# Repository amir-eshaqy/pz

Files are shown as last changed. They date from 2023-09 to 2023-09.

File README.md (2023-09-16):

<h1 align="center" id="title">Arduino Power meter system with Internal PLC</h1>

<p align="center">project-image</p>

<h3><strong>Features</strong></h3>
<ul>
<li>Instant display (voltage, power factor, current, power, frequency)</li>
<li>Ability to set automation in 12 modes and 4 relays (Internal PLC)</li>
<li>Ability to connect to MATLAB software</li>
<li>Ability to connect to the battery</li>
<li>Maximum measurable voltage: 280 volts (two-phase, single-phase)</li>
<li>The maximum measurable current is 100 amperes (using CT 100:1)</li>
<li>The maximum measurable frequency is 60 Hz</li>
<li>Voltage measurement accuracy 0.1 v</li>
<li>Current measurement accuracy 0.2 A</li>
<li>The accuracy of power measurement is 0.4 W</li>
<li>Frequency measurement accuracy of 0.1 Hz</li>
<li>The accuracy of power factor measurement is 0.01%</li>
</ul>
<p><strong>point</strong>:By changing the resistances of <strong>R17</strong> and <strong>R16</strong> in <strong>PZEM</strong>, it is possible to measure the voltage of more than <strong>280 volts</strong> (This is a voltage divider circuit).</p>
<p>For example, if <strong>R17</strong> is equal to <strong>2 megaohms</strong> and <strong>R16</strong> is equal to <strong>750 ohms</strong>, the voltage can be measured up to <strong>500 volts</strong>.</p>
<p>It is also necessary to make changes in the Arduino codes, Additional information in the folder <span style="text-decoration: underline;"><strong>500 volts</strong></span></p>
*point 2:This system also supports Modbus protocol. You can add this potkal to it. And it was in contact with other industrial equipment such as HME and PLCs

____________________________________________________________________________________________
<h3><strong>required pieces ::</strong></h3>
<table border="1">
<tbody>
<tr>
<td>
<h4>Electronic Components</h4>
</td>
<td>
<blockquote>Number</blockquote>
</td>
</tr>
<tr>
<td>Arduino Nano</td>
<td>1</td>
</tr>
<tr>
<td>PZEM004t</td>
<td>1</td>
</tr>
<tr>
<td>Liquid Crystal Displays (Character LCD)</td>
<td>1</td>
</tr>
<tr>
<td>4-channel relay module</td>
<td>1</td>
</tr>
<tr>
<td>push button</td>
<td>5</td>
</tr>
<tr>
<td>switch</td>
<td>1</td>
</tr>
<tr>
<td>Potentiometer 10 kilo ohms</td>
<td>1</td>
</tr>
<tr>
<td>10 kilo ohm resistance</td>
<td>5</td>
</tr>
<tr>
<td>n-channel MOSFET</td>
<td>1</td>
</tr>
</tbody>
</table>

____________________________________________________________________________________________

<h3>Test video&nbsp;</h3>
<p>Connecting power meter to MATLAB and view the data on the chart <a href="https://youtu.be/Np4y_KRA4oQ">https://youtu.be/Np4y_KRA4oQ</a></p>
<p>voltage measurement test <a href="https://youtu.be/dCQaTeNKbkk">https://youtu.be/dCQaTeNKbkk</a></p>
<p>current measurement test <a href="https://youtu.be/r_vkd0LcIXw">https://youtu.be/r_vkd0LcIXw</a></p>
<p>Relay function test <a href="https://youtu.be/pQEmvJ6B6WI">https://youtu.be/pQEmvJ6B6WI</a></p>
<p>&nbsp;</p>
<p>&nbsp;</p>

____________________________________________________________________________________________

<h3>Internal PLC settings :</h3>
<p>To access the settings menu, we must first turn the <strong>MODE</strong> key on and set the required parameters with the <strong>arrow keys</strong>.</p>
<table border="1">
<tbody>
<tr>
<td><strong>parameter in the settings menu</strong></td>
<td><strong>use</strong></td>
</tr>
<tr>
<td>OVER Voltage</td>
<td>Maximum voltage limit</td>
</tr>
<tr>
<td>LOW Voltage</td>
<td>Minimum voltage&nbsp;</td>
</tr>
<tr>
<td>OVER Current</td>
<td>maximum current limit</td>
</tr>
<tr>
<td>LOW Frequency</td>
<td>minimum frequency</td>
</tr>
<tr>
<td>OVER Frequency</td>
<td>Maximum frequency limit</td>
</tr>
<tr>
<td>LOW POWER FACTOR 1</td>
<td>steps, one power factors</td>
</tr>
<tr>
<td>LOW POWER FACTOR 2</td>
<td>steps, two power factors</td>
</tr>
<tr>
<td>LOW POWER FACTOR 3</td>
<td>steps, three power factors</td>
</tr>
<tr>
<td>TMS 1 SET</td>
<td>timer relay one</td>
</tr>
<tr>
<td>TMS 2 SET</td>
<td>timer relay two</td>
</tr>
<tr>
<td>TMS 3 SET</td>
<td>timer relay three</td>
</tr>
<tr>
<td>TMS 4 SET</td>
<td>timer relay four</td>
</tr>
<tr>
<td>R1</td>
<td>set the operation mode of relay one</td>
</tr>
<tr>
<td>R2</td>
<td>set the operation mode of relay two</td>
</tr>
<tr>
<td>R3</td>
<td>set the operation mode of relay three</td>
</tr>
<tr>
<td>R4</td>
<td>set the operation mode of relay four</td>
</tr>
</tbody>
</table>
<p>After making the settings, turn the <strong>MODE</strong> key to the off position so that the data is stored in the <strong>permanent memory</strong> of the controller</p>
<p>* Each relay timer unit is 100 milliseconds</p>
____________________________________________________________________________________________

<h3>A variety of performance modes (R1,R2,R3,R4):</h3>
<p>1- reverse time overcurrent function</p>
2- Additional constant time flow function<br />
3-Overvoltage function<br />
4- voltage reduction function<br />
5- frequency reduction function<br />
6- frequency increase function<br />
7- Function of the function of going out of normal mode (frequency, voltage, current)<br />
8-Function of power factor steps of one<br />
9-Function of power factor steps of two<br />
10- Function of power factor steps of three<br />
11-The operation of voltage out of normal mode<br />
12-&nbsp;Function of frequency out of normal mode</p>

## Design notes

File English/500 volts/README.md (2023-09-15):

<h4>This is the schematic and Arduino code For the power meter, the maximum voltage that can be measured is 500 volts</h4>

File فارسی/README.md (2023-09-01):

# pz
راهنما سیستم انالیزور شبکه برق به همره پی ال سی داخلی

شامل پایان نامه و بروشور  است که با مطالعه کامل انها میتوانید یه پاور انالیزور طراحی کنید.

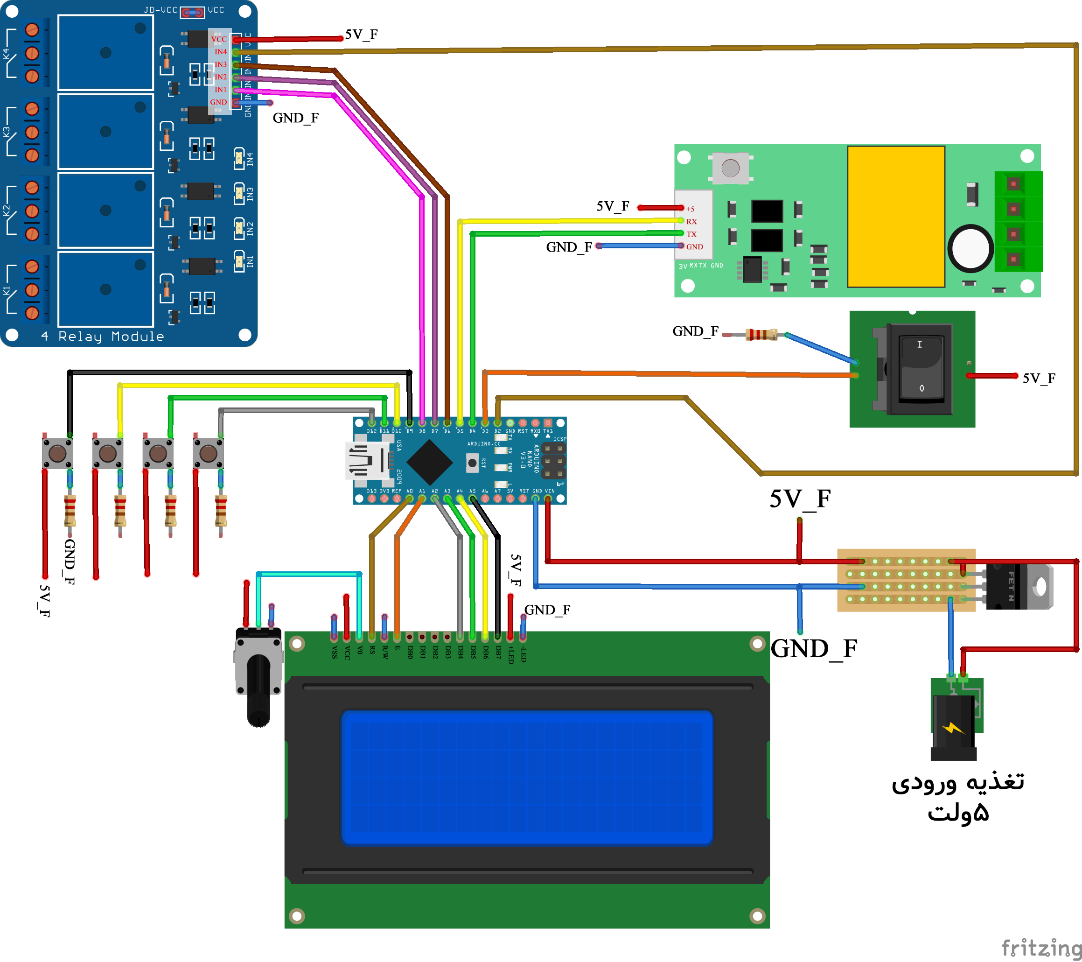
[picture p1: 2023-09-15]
فارسی/schematic.png

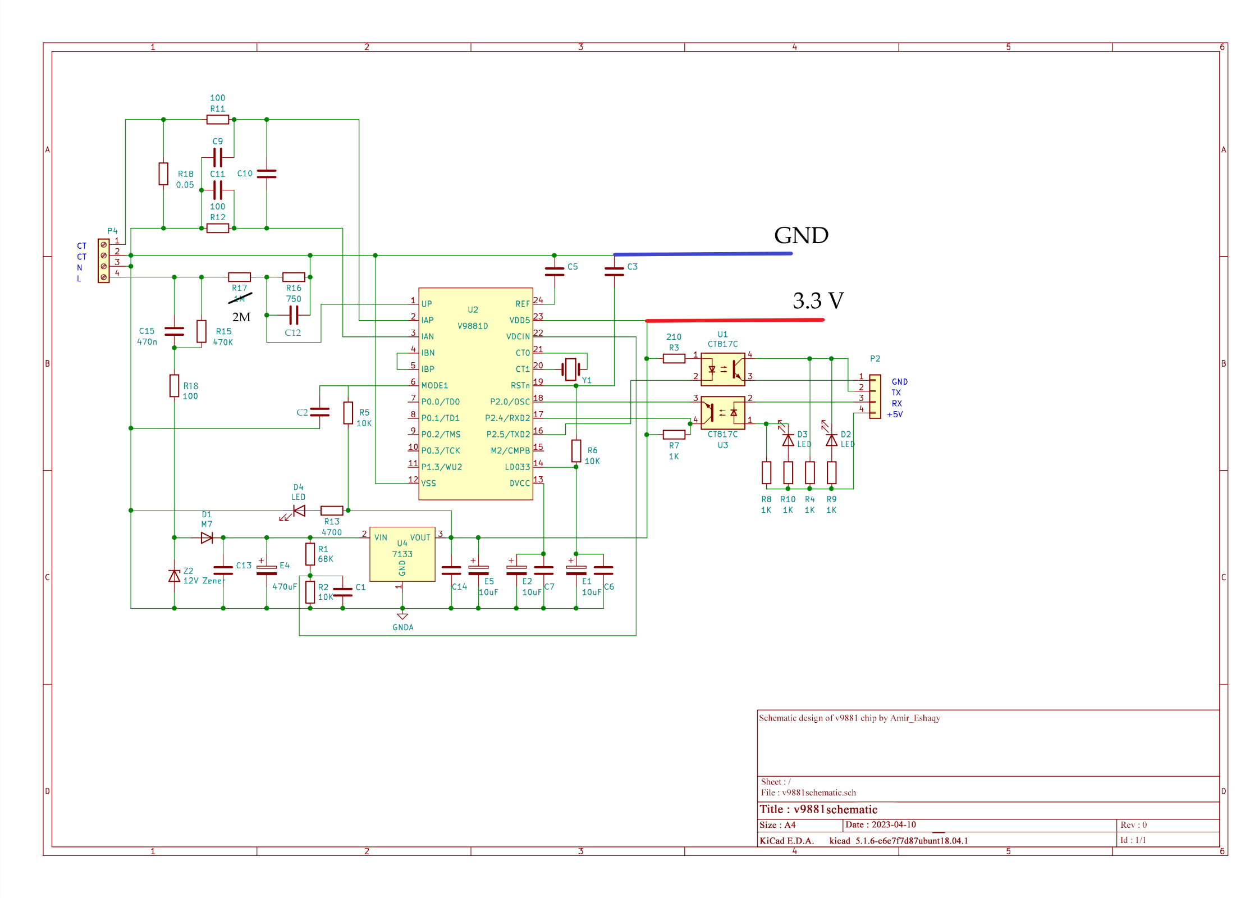
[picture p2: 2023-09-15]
فارسی/500v/PZEM schematic for 500V version.png

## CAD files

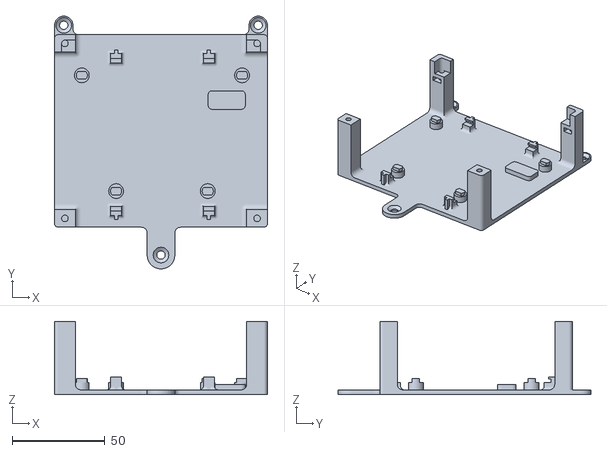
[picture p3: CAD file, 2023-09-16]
English/STL-3d-printer/OSPi_Case_Bottom.stl
115.0 x 136.5 x 39.6

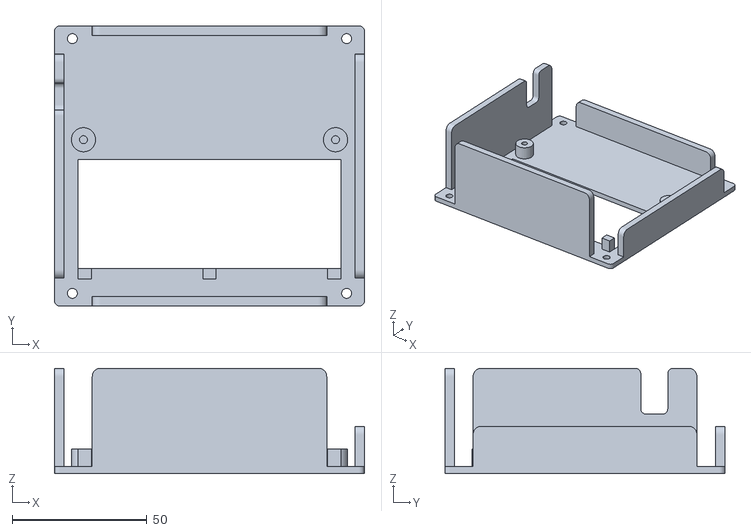
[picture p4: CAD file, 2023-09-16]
English/STL-3d-printer/OSPi_Case_Top.stl
115.0 x 104.0 x 39.1

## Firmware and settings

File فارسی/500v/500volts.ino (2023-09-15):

/*                                                               500v cod
 * Amir_eshaqy
 * 
 * telegram = amir_eshaqy
 * gmail = amir9336146433@gmail.com
 * 
 * Schematic and tutorial files on GitHub
 * GitHub = https://github.com/amir-eshaqy/pz
 * 
 */

#include <PZEM004Tv30.h>
#include <Wire.h>
#include <LiquidCrystal.h>
#include <EEPROM.h>

PZEM004Tv30 pzem(4,5);//arduino
float voltage;
float current;
float power;
float energy;
float frequency;
float pf;
//LiquidCrystal_I2C lcd(0x27,20,4); // set the LCD address to 0x3F for a 16 chars and 2 line display

LiquidCrystal lcd(A0, A1, A2, A3, A4, A5);

byte R1mood=0;
byte R2mood=0;
byte R3mood=0;
byte R4mood=0;


byte mood=3;
byte relly1=8;
byte relly2=7;
byte relly3=6;
byte relly4=2;
byte fclear=0;
int tms_set1=1;
int tms_set2=1;
int tms_set3=1;
int tms_set4=1;
int timeroc1=0;
int timeroc2=0;
int timeroc3=0;
int timeroc4=0;
float ti1=0.00;
float ti2=0.00;
float ti3=0.00;
float ti4=0.00;
byte O_V=0;
byte L_V=0;
byte O_C=0;
byte L_F=0;
byte O_F=0;
float L_PF1=0.90;
float L_PF2=0.85;
float L_PF3=0.80;
//Input & Button Logic
const int numOfInputs = 4;
const int inputPins[numOfInputs] = {12,11,10,9};
int inputState[numOfInputs];
int lastInputState[numOfInputs] = {LOW,LOW,LOW,LOW};
bool inputFlags[numOfInputs] = {LOW,LOW,LOW,LOW};
long lastDebounceTime[numOfInputs] = {0,0,0,0};
long debounceDelay = 5;

//LCD Menu Logic
const int numOfScreens = 16;
int currentScreen = 0;
String screens[numOfScreens][2] = {{"Over Voltage","Volts"}, {"Low Voltage","Volts"}, 
{"Over Current","Amper"},{"Low Frequency","Hz"},{"Over Frequency","Hz"}, {"LOW POWER FACTOR 1", "CosFi"}, {"LOW POWER FACTOR 2", "CosFi"}, {"LOW POWER FACTOR 3", "CosFi"},{"TMS1 SET", " "},{"TMS2 SET", " "},{"TMS3 SET", ""},{"TMS4 SET", " "},{"R1_Mood", " "},{"R2_Mood", " "},{"R3_Mood", " "},{"R4_Mood", " "}};

float parameters[numOfScreens];




void setup() {
 O_V=EEPROM.read(1);
 L_V=EEPROM.read(2);
 O_C=EEPROM.read(3);
 L_F=EEPROM.read(4);
 O_F=EEPROM.read(5);
 EEPROM.get(10,L_PF1);
 EEPROM.get(30,L_PF2);
 EEPROM.get(50,L_PF3);
 EEPROM.get(70,tms_set1);
 EEPROM.get(100,tms_set2);
 EEPROM.get(130,tms_set3);
 EEPROM.get(160,tms_set4);
 R1mood=EEPROM.read(190);
 R2mood=EEPROM.read(191);
 R3mood=EEPROM.read(192);
 R4mood=EEPROM.read(193);
 parameters[0]=float(O_V);
  parameters[1]=float(L_V);
  parameters[2]=float(O_C);
  parameters[3]=float(L_F);
  parameters[4]=float(O_F);
  parameters[5]=L_PF1;
  parameters[6]=L_PF2;
  parameters[7]=L_PF3;
  parameters[8]=tms_set1;
  parameters[9]=tms_set2;
  parameters[10]=tms_set3;
  parameters[11]=tms_set4;
  parameters[12]=R1mood;
  parameters[13]=R2mood;
  parameters[14]=R3mood;
  parameters[15]=R4mood;
    Serial.begin(115200);
//  lcd.begin();
  //lcd.init();                      // initialize the lcd 
  
  lcd.begin(20, 4);
  
//  lcd.backlight();
      lcd.clear();
       lcd.setCursor(5, 1);
       lcd.print("AMIR_ESHAQY");
      delay(2000);
      lcd.clear();
    // Uncomment in order to reset the internal energy counter
    // pzem.resetEnergy()
 for(int i = 0; i < numOfInputs; i++) {
    pinMode(inputPins[i], INPUT);
    digitalWrite(inputPins[i], HIGH); // pull-up 20k
  }
  pinMode(mood,INPUT);
  pinMode(relly1,OUTPUT);
  pinMode(relly2,OUTPUT);
  pinMode(relly3,OUTPUT);
  pinMode(relly4,OUTPUT);
  
  digitalWrite(relly4,HIGH);
  digitalWrite(relly3,HIGH);
  digitalWrite(relly2,HIGH);
  digitalWrite(relly1,HIGH);
}





///////////////////////////////////////////////////////////////////////////////////////////////
void loop(){
  if(digitalRead(mood)==HIGH){
 
 save_eep();
 Reeding_par();
// rellay();
relay_new();
   // Serial.println();
    delay(100);
}else{ 
  fclear=0;
  setInputFlags();
  resolveInputFlags();
  }
}

void setInputFlags() {
  for(int i = 0; i < numOfInputs; i++) {
    int reading = digitalRead(inputPins[i]);
    if (reading != lastInputState[i]) {
      lastDebounceTime[i] = millis();
    }
    if ((millis() - lastDebounceTime[i]) > debounceDelay) {
      if (reading != inputState[i]) {
        inputState[i] = reading;
        if (inputState[i] == HIGH) {
          inputFlags[i] = HIGH;
        }
      }
    }
    lastInputState[i] = reading;
  }
}

void resolveInputFlags() {
  for(int i = 0; i < numOfInputs; i++) {
    if(inputFlags[i] == HIGH) {
      inputAction(i);
      inputFlags[i] = LOW;
      printScreen();
    }
  }
}

void inputAction(int input) {
  if(input == 0) {
    if (currentScreen == 0) {
      currentScreen = numOfScreens-1;
    }else{
      currentScreen--;
    }
  }else if(input == 1) {
    if (currentScreen == numOfScreens-1) {
      currentScreen = 0;
    }else{
      currentScreen++;
    }
  }else if(input == 2) {
    parameterChange(0);
  }else if(input == 3) {
    parameterChange(1);
  }
}

void parameterChange(int key) {
   if(key == 0 && currentScreen>=5&& currentScreen<=7) {
    parameters[currentScreen]=parameters[currentScreen]+0.01;
  }else if(key == 1 && currentScreen>=5&& currentScreen<=7) {
    parameters[currentScreen]=parameters[currentScreen]-0.01;
  }else if(key == 0 && currentScreen!=5) {
    parameters[currentScreen]++;
  }else if(key == 1 && currentScreen!=5) {
    parameters[currentScreen]--;}
O_V=byte(parameters[0]);
L_V=byte(parameters[1]);
O_C=byte(parameters[2]);
L_F=byte(parameters[3]);
O_F=byte(parameters[4]);
L_PF1=parameters[5];
L_PF2=parameters[6];
L_PF3=parameters[7];
tms_set1=parameters[8];
tms_set2=parameters[9];
tms_set3=parameters[10];
tms_set4=parameters[11];
R1mood=parameters[12];
R2mood=parameters[13];
R3mood=parameters[14];
R4mood=parameters[15];}

void printScreen() {
  lcd.clear();
  lcd.print(screens[currentScreen][0]);
  lcd.setCursor(0,1);
  lcd.print(parameters[currentScreen]);
  lcd.print(" ");
  lcd.print(screens[currentScreen][1]);
}
////////////////////////////pzem reeding prametr
void Reeding_par(){
  
      
  //  Serial.print("Custom Address:");
   // Serial.println(pzem.readAddress(), HEX);

    // Read the data from the sensor
    ////////////////////////////V500///////////////////////
     float x34=pzem.voltage();
    // Serial.println(x34);
     if(x34<57){
      voltage= pzem.voltage()*1.75;} 
     if(x34<114&&x34>57){
     voltage= pzem.voltage()*1.7701;}
     if(x34<170&&x34>114){
     voltage= pzem.voltage()*1.767;}
     if(x34<227&&x34>170){
     voltage= pzem.voltage()*1.763;}
     if(x34<285&&x34>227){
     voltage= pzem.voltage()*1.76;}
     /////////////////////////////V500//////////////////////////////

    current = pzem.current();
    power = pzem.power();
    energy = pzem.energy();
    frequency = pzem.frequency();
    //pf = pzem.pf();
    if(pzem.pf()<0.1){
    pf=1.00;
    }else if(pzem.pf()>0.99){
    pf=0.00;
    }else{
    pf=pzem.pf();  
    }
    
   // Check if the data is valid
    if(isnan(voltage)){
        //Serial.println("Error reading voltage");
        lcd.clear();   
                lcd.setCursor(0, 1);
                lcd.print("Error readingVoltage");
    } else if (isnan(current)) {
      //  Serial.println("Error reading current");
        lcd.clear();   
                lcd.setCursor(0, 1);
                lcd.print("Error readingCurrent");
    } else if (isnan(power)) {
       // Serial.println("Error reading power");
        lcd.clear();   
               lcd.setCursor(0, 1);
               lcd.print("Error reading Power");
    } else if (isnan(energy)) {
       // Serial.println("Error reading energy");
        lcd.clear();   
               lcd.setCursor(0, 1);
               lcd.print("Error reading Energy");
    } else if (isnan(frequency)) {
       // Serial.println("Error reading frequency");
        lcd.clear();   
               lcd.setCursor(0, 1);
               lcd.print("Error Read Frequency");
    } else if (isnan(pf)) {
      //  Serial.println("Error reading power factor");
        lcd.clear();   
               lcd.setCursor(0, 1);
               lcd.print("ErrorReadPowerFactor");
    } else {
//Serial.print(x);Serial.print(",");

        // Print the values to the Serial console
        Serial.print(voltage);Serial.print(",");
      //  Serial.print("Voltage: ");      Serial.print(voltage);      Serial.println("V");
        lcd.setCursor(0,0);             lcd.print("V:");            lcd.setCursor(2,0);           lcd.print(voltage);
      //  Serial.print("Current: ");      Serial.print(current);      Serial.println("A");
        Serial.print(current);Serial.print(",");
        lcd.setCursor(10,0);             lcd.print("I:");            lcd.setCursor(12,0);         lcd.print(current);
      //  Serial.print("Power: ");        Serial.print(power);        Serial.println("W");
        Serial.print(power);Serial.print(",");
        lcd.setCursor(0,1);             lcd.print("W:");            lcd.setCursor(2,1);           lcd.print(power);     lcd.print("    ");
      //  Serial.print("Energy: ");       Serial.print(energy,3);     Serial.println("kWh");
        Serial.print(energy,3);Serial.print(",");
        lcd.setCursor(10,1);            lcd.print("KWh:");          lcd.setCursor(14,1);          lcd.print(energy,3);  lcd.print(" ");
      //  Serial.print("Frequency: ");    Serial.print(frequency, 1); Serial.println("Hz");
        Serial.print(frequency, 1);Serial.print(",");
        lcd.setCursor(0,2);             lcd.print("Hz:");            lcd.setCursor(3,2);           lcd.print(frequency, 1);
        //Serial.print("PF: ");           Serial.println(pf);
      
        lcd.setCursor(10,2);            lcd.print("PF:");           
      /*   if(pf<0.1){
          
      Serial.println("1");
        lcd.setCursor(13,2);         lcd.print(1);
        pf=1;
          }else{
        Serial.println(pf);
        lcd.setCursor(13,2);         lcd.print(pf);}*/
        Serial.println(pf);
        lcd.setCursor(13,2);         lcd.print(pf);
        
        lcd.setCursor(0,3);             lcd.print("TMS1=");           lcd.print(tms_set1);       
}
        ////////////////////////////////////////////////////////////////////////////////////////////////////////////////////
       

}
  void save_eep(){
     if(fclear==0){
  EEPROM.update(1, O_V);
  EEPROM.update(2, L_V);
  EEPROM.update(3, O_C);
  EEPROM.update(4, L_F);
  EEPROM.update(5, O_F);
  EEPROM.put(10, L_PF1);
  EEPROM.put(30, L_PF2);
  EEPROM.put(50, L_PF3);
  EEPROM.put(70,tms_set1);
  EEPROM.put(100,tms_set2);
  EEPROM.put(130,tms_set3);
  EEPROM.put(160,tms_set4);
  EEPROM.put(190,R1mood);
  EEPROM.put(191,R2mood);
  EEPROM.put(192,R3mood);
  EEPROM.put(193,R4mood);
  
  lcd.clear();
  fclear=1;}
    }
void relay_new(){
switch (R1mood) {
    case 1:
    //tms_On
    if(current>O_C){
    timeroc1++;
    ti1=(0.14*float(tms_set1))/(pow(current/float(O_C),0.02)-1);
    if(timeroc1>=ti1){
    timeroc1==ti1;
      digitalWrite(relly1,LOW);
      }
   }else{
      digitalWrite(relly1,HIGH);
       timeroc1=0;  
         }
   break;
   case 2:
      if(current>O_C){
      timeroc1++;
    if(timeroc1>=tms_set1){
      timeroc1==tms_set1;
        digitalWrite(relly1,LOW);
      }
   }else{
        digitalWrite(relly1,HIGH);
       timeroc1=0;  
         }
    break;
    case 3:
      if(voltage>O_V){
      timeroc1++;
    if(timeroc1>=tms_set1){
      timeroc1==tms_set1;
        digitalWrite(relly1,LOW);
      }
   }else{
       digitalWrite(relly1,HIGH);
       timeroc1=0;  
         }
   break;
   case 4:
    if(voltage<L_V){
        timeroc1++;
    if(timeroc1>=tms_set1){
        timeroc1==tms_set1;
        digitalWrite(relly1,LOW);
      }
   }else{
        digitalWrite(relly1,HIGH);
        timeroc1=0;  
         }
  break;
  case 5:
    if(frequency<L_F){
    timeroc1++;
    if(timeroc1>=tms_set1){
       timeroc1==tms_set1;
       digitalWrite(relly1,LOW);
      }
   }else{
       digitalWrite(relly1,HIGH);
       timeroc1=0;  
         }
  break;
  case 6:
    if(frequency>O_F){
    timeroc1++;
    if(timeroc1>=tms_set1){
      timeroc1==tms_set1;
      digitalWrite(relly1,LOW);
      }
   }else{
      digitalWrite(relly1,HIGH);
      timeroc1=0;  
         }
  break;
  case 7:
    if(voltage>O_V||voltage<L_V||current>O_C||frequency<L_F||frequency>O_F){
    timeroc1++;
    if(timeroc1>=tms_set1){
      timeroc1==tms_set1;
      digitalWrite(relly1,LOW);
      }
   }else{
      digitalWrite(relly1,HIGH);
      timeroc1=0;  
         }
  break;
  case 8:
    if(pf<L_PF1){
    timeroc1++;
    if(timeroc1>=tms_set1){
      timeroc1==tms_set1;
        digitalWrite(relly1,LOW);
      }
   }else{
        digitalWrite(relly1,HIGH);
       timeroc1=0;  
         }
  break;
  case 9:
    if(pf<L_PF2){
    timeroc1++;
    if(timeroc1>=tms_set1){
      timeroc1==tms_set1;
        digitalWrite(relly1,LOW);
      }
   }else{
        digitalWrite(relly1,HIGH);
       timeroc1=0;  
         }
  break;
  case 10:
    if(pf<L_PF3){
    timeroc1++;
    if(timeroc1>=tms_set1){
      timeroc1==tms_set1;
        digitalWrite(relly1,LOW);
      }
   }else{
        digitalWrite(relly1,HIGH);
        timeroc1=0;  
         }
  break;
  case 11:
    if(voltage>O_V||voltage<L_V){
    timeroc1++;
    if(timeroc1>=tms_set1){
        timeroc1==tms_set1;
        digitalWrite(relly1,LOW);
      }
   }else{
        digitalWrite(relly1,HIGH);
        timeroc1=0;  
         }
  break;
  case 12:
    if(frequency<L_F||frequency>O_F){
    timeroc1++;
    if(timeroc1>=tms_set1){
        timeroc1==tms_set1;
        digitalWrite(relly1,LOW);
      }
   }else{
        digitalWrite(relly1,HIGH);
        timeroc1=0;  
         }
  break;
 default: 
      digitalWrite(relly1,HIGH);
  break;
  }
switch (R2mood) {
    case 1:
    //tms_On
    if(current>O_C){
    timeroc2++;
    ti2=(0.14*float(tms_set2))/(pow(current/float(O_C),0.02)-1);
    //Serial.println(tms);
    if(timeroc2>=ti2){
     timeroc2==ti2;
   // Serial.println("on erlly");
      digitalWrite(relly2,LOW);
      }
   }else{
      digitalWrite(relly2,HIGH);
       timeroc2=0;  
         }
      break;
    case 2:
      if(current>O_C){
    timeroc2++;
    if(timeroc2>=tms_set2){
      timeroc2==tms_set2;
      digitalWrite(relly2,LOW);
      }
   }else{
      digitalWrite(relly2,HIGH);
       timeroc2=0;  
         }
      break;
    case 3:
    if(voltage>O_V){
      timeroc2++;
    if(timeroc2>=tms_set2){
      timeroc2==tms_set2;
      digitalWrite(relly2,LOW);
      }
   }else{
      digitalWrite(relly2,HIGH);
       timeroc2=0;  
         }
  break;
    case 4:
    if(voltage<L_V){
      timeroc2++;
    if(timeroc2>=tms_set2){
      timeroc2==tms_set2;
      digitalWrite(relly2,LOW);
      }
   }else{
      digitalWrite(relly2,HIGH);
       timeroc2=0;  
         }
  break;
    case 5:
    if(frequency<L_F){
       timeroc2++;
    if(timeroc2>=tms_set2){
      timeroc2==tms_set2;
      digitalWrite(relly2,LOW);
      }
   }else{
      digitalWrite(relly2,HIGH);
       timeroc2=0;  
         }
  break;
    case 6:
     if(frequency>O_F){
       timeroc2++;
    if(timeroc2>=tms_set2){
      timeroc2==tms_set2;
      digitalWrite(relly2,LOW);
      }
   }else{
      digitalWrite(relly2,HIGH);
       timeroc2=0;  
         }
  break;
    case 7:
    if(voltage>O_V||voltage<L_V||current>O_C||frequency<L_F||frequency>O_F){
    timeroc2++;
    //Serial.println(tms);
    if(timeroc2>=tms_set2){
      timeroc2==tms_set2;
   // Serial.println("on erlly");
      digitalWrite(relly2,LOW);
      }
   }else{
      digitalWrite(relly2,HIGH);
       timeroc2=0;  
         }
  break;
    case 8:
     if(pf<L_PF1){
       timeroc2++;
    if(timeroc2>=tms_set2){
      timeroc2==tms_set2;
      digitalWrite(relly2,LOW);
      }
   }else{
      digitalWrite(relly2,HIGH);
       timeroc2=0;  
         }
  break;
    case 9:
     if(pf<L_PF2){
       timeroc2++;
    if(timeroc2>=tms_set2){
      timeroc2==tms_set2;
      digitalWrite(relly2,LOW);
      }
   }else{
      digitalWrite(relly2,HIGH);
       timeroc2=0;  
         }
  break;
    case 10:
     if(pf<L_PF3){
      timeroc2++;
    if(timeroc2>=tms_set2){
      timeroc2==tms_set2;
      digitalWrite(relly2,LOW);
      }
   }else{
      digitalWrite(relly2,HIGH);
       timeroc2=0;  
         }
  break;
    case 11:
     if(voltage>O_V||voltage<L_V){
     timeroc2++;
    if(timeroc2>=tms_set2){
      timeroc2==tms_set2;
      digitalWrite(relly2,LOW);
      }
   }else{
      digitalWrite(relly2,HIGH);
       timeroc2=0;  
         }
  break;
    case 12:
     if(frequency<L_F||frequency>O_F){
       timeroc2++;
    if(timeroc2>=tms_set2){
      timeroc2==tms_set2;
      digitalWrite(relly2,LOW);
      }
   }else{
      digitalWrite(relly2,HIGH);
       timeroc2=0;  
         }
  break;
 default: 
      digitalWrite(relly2,HIGH);
    break;
  }
  switch (R3mood) {
    case 1:
    //tms_On
    if(current>O_C){
    timeroc3++;
    ti3=(0.14*float(tms_set3))/(pow(current/float(O_C),0.02)-1);
    //Serial.println(tms);
    if(timeroc3>=ti3){
     timeroc3==ti3;
   // Serial.println("on erlly");
      digitalWrite(relly3,LOW);
      }
   }else{
      digitalWrite(relly3,HIGH);
       timeroc3=0;  
         }
      break;
    case 2:
      if(current>O_C){
    timeroc3++;
    if(timeroc3>=tms_set3){
      timeroc3==tms_set3;
      digitalWrite(relly3,LOW);
      }
   }else{
      digitalWrite(relly3,HIGH);
       timeroc3=0;  
         }
      break;
    case 3:
    if(voltage>O_V){
      timeroc3++;
    if(timeroc3>=tms_set3){
      timeroc3==tms_set3;
      digitalWrite(relly3,LOW);
      }
   }else{
      digitalWrite(relly3,HIGH);
       timeroc3=0;  
         }
  break;
    case 4:
    if(voltage<L_V){
      timeroc3++;
    if(timeroc3>=tms_set3){
      timeroc3==tms_set3;
      digitalWrite(relly3,LOW);
      }
   }else{
      digitalWrite(relly3,HIGH);
       timeroc3=0;  
         }
  break;
    case 5:
    if(frequency<L_F){
     timeroc3++;
    if(timeroc3>=tms_set3){
      timeroc3==tms_set3;
      digitalWrite(relly3,LOW);
      }
   }else{
      digitalWrite(relly3,HIGH);
       timeroc3=0;  
         }
  break;
    case 6:
     if(frequency>O_F){
      timeroc3++;
    if(timeroc3>=tms_set3){
      timeroc3==tms_set3;
      digitalWrite(relly3,LOW);
      }
   }else{
      digitalWrite(relly3,HIGH);
       timeroc3=0;  
         }
  break;
    case 7:
    if(voltage>O_V||voltage<L_V||current>O_C||frequency<L_F||frequency>O_F){
    timeroc3++;
    //Serial.println(tms);
    if(timeroc3>=tms_set3){
      timeroc3==tms_set3;
   // Serial.println("on erlly");
      digitalWrite(relly3,LOW);
      }
   }else{
      digitalWrite(relly3,HIGH);
       timeroc3=0;  
         }
  break;
    case 8:
     if(pf<L_PF1){
      timeroc3++;
    if(timeroc3>=tms_set3){
      timeroc3==tms_set3;
      digitalWrite(relly3,LOW);
      }
   }else{
      digitalWrite(relly3,HIGH);
       timeroc3=0;  
         }
  break;
    case 9:
     if(pf<L_PF2){
     timeroc3++;
    if(timeroc3>=tms_set3){
      timeroc3==tms_set3;
      digitalWrite(relly3,LOW);
      }
   }else{
      digitalWrite(relly3,HIGH);
       timeroc3=0;  
         }
  break;
    case 10:
     if(pf<L_PF3){
     timeroc3++;
    if(timeroc3>=tms_set3){
      timeroc3==tms_set3;
      digitalWrite(relly3,LOW);
      }
   }else{
      digitalWrite(relly3,HIGH);
       timeroc3=0;  
         }
  break;
    case 11:
     if(voltage>O_V||voltage<L_V){
      timeroc3++;
    if(timeroc3>=tms_set3){
      timeroc3==tms_set3;
      digitalWrite(relly3,LOW);
      }
   }else{
      digitalWrite(relly3,HIGH);
       timeroc3=0;  
         }
  break;
    case 12:
     if(frequency<L_F||frequency>O_F){
   timeroc3++;
    if(timeroc3>=tms_set3){
      timeroc3==tms_set3;
      digitalWrite(relly3,LOW);
      }
   }else{
      digitalWrite(relly3,HIGH);
       timeroc3=0;  
         }
  break;
 default: 
      digitalWrite(relly3,HIGH);
    break;
  }
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

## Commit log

2023-08-24 فایل پی دی اف راهنمت
    فایل پی دی اف راهنمت
2023-08-24 فایل PDF راهنما
    فایل PDF راهنمت
2023-09-01 پایان نامه
    پایان نامه شامل تحقیقات انجام شده تا ساخت این محصول
2023-09-01 بروشور(معرفی و راهنمای استفاده)
    بروشور
2023-09-15 کد آردوینو
    این کد برای اردوینو نانو است کد را با برنامه اردوینو باز کنید و سپس در برد خود کامپایل کنید
2023-09-15 کد متلب
    این کد را در نرم افزار متلب اجرا کنید حتما پورت کحام و باوت ریت را درست تنظیم کنید
2023-09-15 س
    س
2023-09-15 Create فارسی
    راهنما و اطلاعات به زبان فارسی
2023-09-15 Create فارسی
2023-09-15 Update and rename power_V7.ino to فارسی/power_V7.ino
    کد آردوینو پاور آنالیزور
2023-09-15 کد متلب
    این کد را در نرم افزار متلب اجرا کنید حتما پورت کحام و باوت ریت را درست تنظیم کنی
2023-09-15 Add files via upload
    پایان نامه شامل تحقیقات انجام شده تا ساخت این محصول است
    متاسفانه پس از تلاش های فراوان برای ثبت این پایان نامه در سایت های ثبت پایان نامه و تحقیقات ایران نتوانستیم این پایان نامه را در هیچ مرجعی ثبت کنیم
    لطفا پس از مشاهده نظرات خود را با من در میان بگذارید
    با تشکر
    Amir_Eshaqy
2023-09-15 Arduino code
    Code written in C language with Arduino IDE
2023-09-15 Update and rename power_V7.ino to English/power_V7.ino
2023-09-15 Update power_V7.ino
    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
2023-09-15 MATLAB code
    to connect Arduino and MATLAB
2023-09-15 schematic
    In this photo, the connection of electrical parts is shown
2023-09-15 شماتیک
    در این عکس شماتیک اتصالات قطعات نشان داده شده است
2023-09-15 500v Power meter
    500 volts Arduino Power meter system with Internal PLC
2023-09-15 PZEM schematic for 500V version
    PZEM schematic for 500V version
2023-09-16 STL 3d printer file
    [OSPi_Case_Bottom.stl, OSPi_Case_Top.stl]
2023-09-16 شماتیک تغییرات PZEM
    برای اندازه گیری 500ولت
